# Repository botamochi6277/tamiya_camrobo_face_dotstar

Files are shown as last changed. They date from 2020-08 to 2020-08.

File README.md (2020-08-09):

# TAMIYA CAMROBO FACE DOTSTAR

FRONT

BACK

An extension board for the face of [TAMIYA Cam-Program Robot](https://www.tamiya.com/english/products/70227/index.htm). 
This board has RGB LEDs and an audio amp.
This board is designed for Raspberry Pi.

- LED: SK9822, compatible chip of APA102. It is a RGB LED including a controller communicate with SPI. 
- Audio AMP: [AKIZUKI AMP Module](http://akizukidenshi.com/catalog/g/gK-08217/) using PAM8012. 
- Speaker: Small speaker you can buy from [AKIZUKI](http://akizukidenshi.com/catalog/g/gP-10128/). You need replace it because the speaker works in 3V (I failed to select.)

The board in v1.0 (photo version) have no wire between `IN-` and `GND`. I added wire for the connection. 

LICENCE: [Open Source Hardware](https://www.oshwa.org/definition/)

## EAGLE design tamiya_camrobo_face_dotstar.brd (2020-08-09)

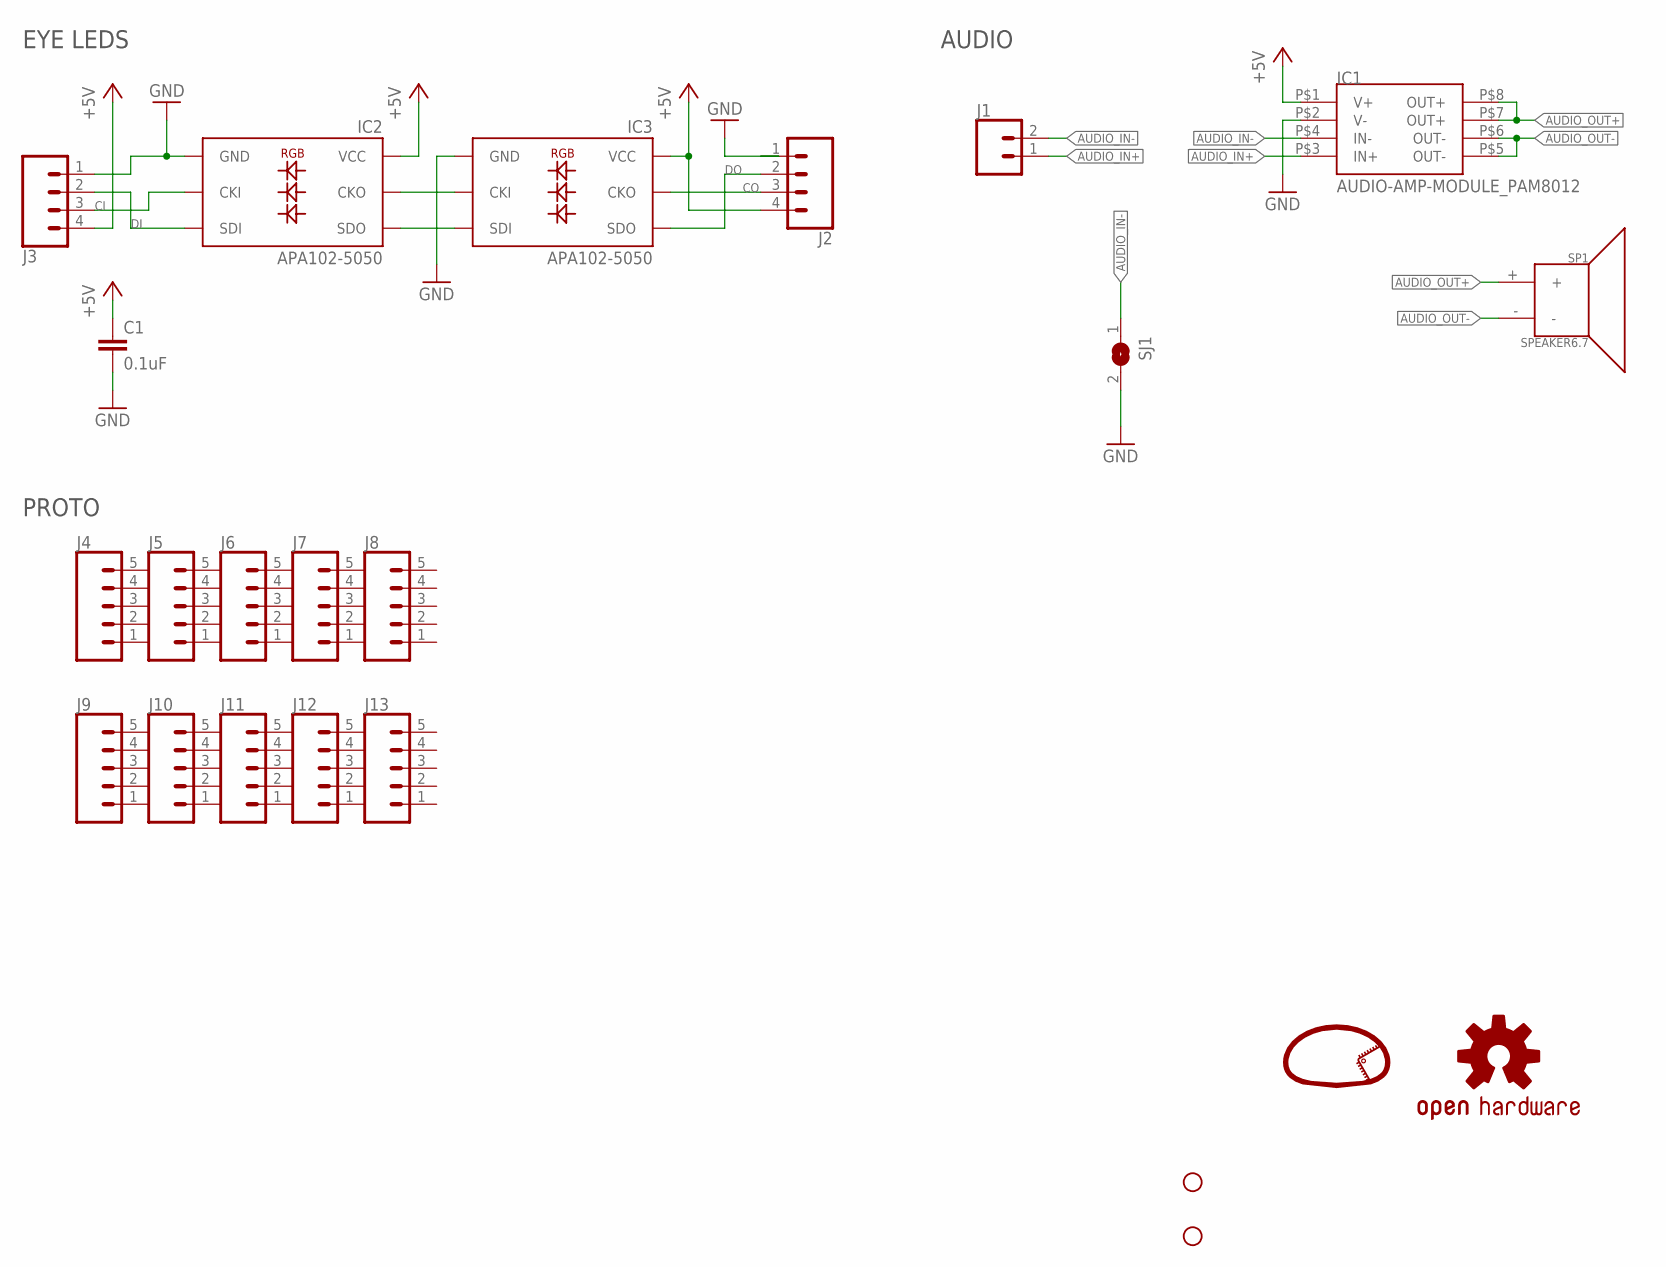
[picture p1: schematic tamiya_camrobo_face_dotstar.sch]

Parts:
C1: 0.1uF; C1608
H1, H2: STAND-OFF
IC1: AUDIO-AMP-MODULE_PAM8012; AE-PAM8012
IC2, IC3: APA102-5050; APA102C-5050
J1: CONN_02; 1X02
J2, J3: CONN_04; 1X04
J4, J5, J6, J7, J8, J9, J10, J11, J12, J13: CONN_05NO_SILK; 1X05_NO_SILK
LOGO1: LOGO
LOGO2: OSHW-LOGOS; OSHW-LOGO-S
SJ1: SJ
SP1: SPEAKER6.7; SPEAKER-6.7MM

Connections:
+5V: C1.1, IC1.P$1 (V+), IC2.VCC, IC3.VCC, J2.4, J3.4
AUDIO_IN+: IC1.P$3 (IN+), J1.1
AUDIO_IN-: IC1.P$4 (IN-), J1.2, SJ1.1
AUDIO_OUT+: IC1.P$7 (OUT+), IC1.P$8 (OUT+), SP1.+
AUDIO_OUT-: IC1.P$5 (OUT-), IC1.P$6 (OUT-), SP1.-
CI: IC2.CKI, J3.3
CO: IC3.CKO, J2.3
DI: IC2.SDI, J3.2
DO: IC3.SDO, J2.2
GND: C1.2, IC1.P$2 (V-), IC2.GND, IC3.GND, J2.1, J3.1, SJ1.2
unnamed: IC2.SDO, IC3.SDI
unnamed: IC2.CKO, IC3.CKI

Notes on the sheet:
EYE LEDS
AUDIO
PROTO

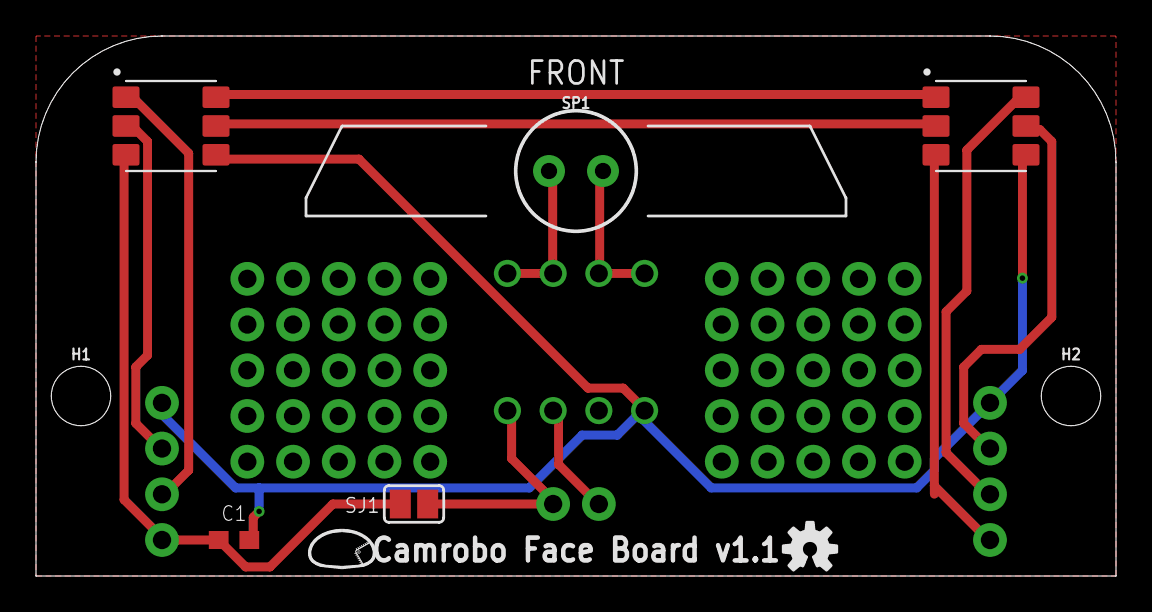
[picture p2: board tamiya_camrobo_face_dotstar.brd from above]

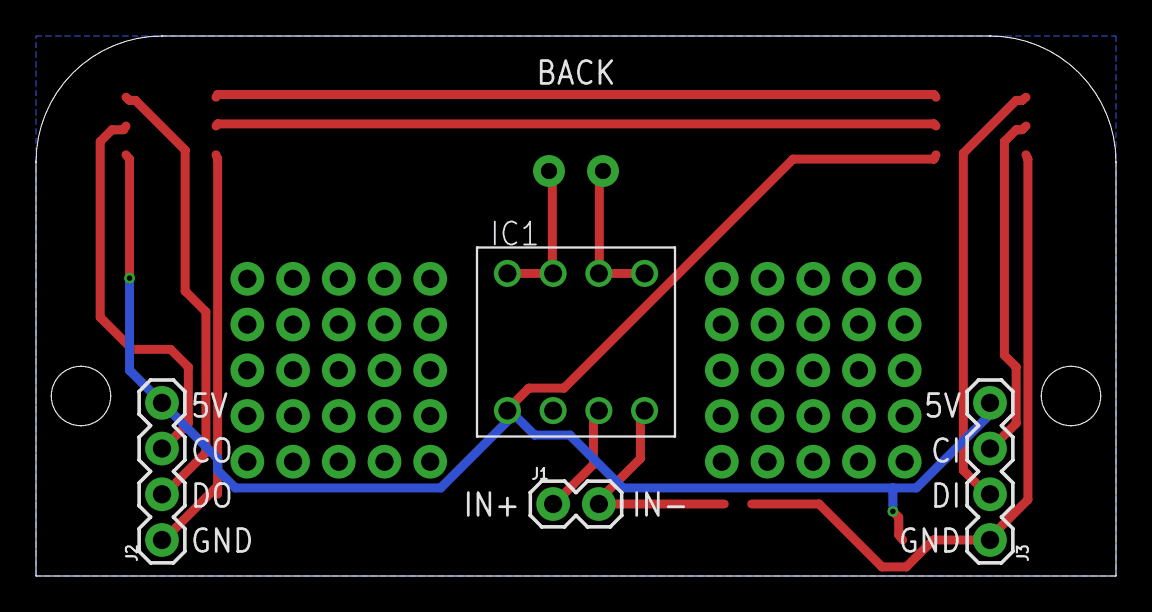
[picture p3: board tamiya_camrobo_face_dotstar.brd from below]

Board: 2 copper layers, 60.0 x 30.0 mm, 23 parts (4 on the bottom side), 12 nets.

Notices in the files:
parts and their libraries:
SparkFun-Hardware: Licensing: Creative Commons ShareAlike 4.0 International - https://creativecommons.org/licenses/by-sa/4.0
